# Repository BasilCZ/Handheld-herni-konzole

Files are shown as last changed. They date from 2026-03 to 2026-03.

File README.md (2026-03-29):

# Vlastní Handheld herní konzole 

Fotka dokončené konzole

## O projektu
Tento repozitář obsahuje seznam všech součástek, 3D modely a zdrojové kódy pro vlastnoručně postavenou přenosnou herní konzoli poháněnou počítačem **Raspberry Pi 5**.

### Technické úkoly, které jsem na projektu řešil:
* Návrh a 3D tisk vlastní krabičky pro konzoli.
* Propojení **Raspberry Pi 5** s 5" kapacitním dotykovým displejem a 15 fyzickými mikrospínači přes GPIO rozhraní.
* Návrh napájení pomocí 3,7V 8000mAh Li-Pol baterie.
* Zapojení audia (8Ω 2W reproduktor Waveshare) a řešení odvodu tepla (52Pi aktivní chladič).
* Vývoj hlavní softwarové logiky a ovládání v **Pythonu**.

## Struktura repozitáře

### Hardware
Fyzické komponenty a návrh zapojení najdete ve složce `/hardware/`:
* `Seznam součástek.csv` a `Seznam součástek.xlsx` - Kompletní seznam součástek + kde je koupit/sehnat

### 3D Modely
Soubory pro výrobu krabičky najdete ve složce `/3d-modely/`:
* `Dolní část krabičky.stl` a `Horní část krabičky.stl` - Modely připravené pro 3D tisk.

### Software (Zdrojové kódy)
* `/src/` - Zde se nachází zdrojový kód, který spravuje veškerou logiku ovladače

### Docs (Dokumentace)
* Ukazuje postupný vývoj herní konzole

## Použité technologie
* **Hardware:** Raspberry Pi 5 (Single Board Computer), GPIO rozhraní, Pájení elektroniky
* **Software:** Python, OS Linux (Raspberry Pi OS)
* **Konstrukce:** 3D modelování, 3D tisk

---
*Vytvořil Ondřej Kučera (2025/2026) - Student IT na SPŠE Ječná*

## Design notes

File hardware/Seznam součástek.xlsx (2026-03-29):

Množství | Název součástky | Odkaz | Poznámky
1 | Raspberry Pi 5 - 8GB RAM | https://rpishop.cz/raspberry-pi-5/6498-raspberry-pi-5-8gb-ram.html | Stačí 4GB verze
2 | Li-Pol nabíjecí baterie 3,7 V / 8000 mAh | https://rpishop.cz/535791/li-pol-nabijeci-baterie-37-v-8000-mah/ | Stačí jen jedna
1 | 52Pi - Tenký chladicí ventilátor pro Raspberry Pi 5 | https://rpishop.cz/625761/52pi-tenky-chladici-ventilator-pro-raspberry-pi-5/
15 | Mikrospínač, černá | https://rpishop.cz/tlacitka-spinace/1320-mikrospinac-cerna.html
1 | Raspberry Pi Touch Display 2 - 5”, 720 × 1280, kapacitní, DSI | https://rpishop.cz/610722/raspberry-pi-touch-display-2-5-portrait/
1 | Raspberry Pi 5 RTC baterie | https://rpishop.cz/knoflikove/6499-raspberry-pi-5-rtc-baterie.html | Není potřeba
1 | Raspberry Pi 5 Display Cable Standard - Mini, 300 mm | https://rpishop.cz/mipi/6505-raspberry-pi-5-display-cable-standard-mini-300-mm.html | Kabel který je dodán s displejem není dostatečně dlouhý, proto je potřeba jej dokoupit
1 | Waveshare 8Ω 2W Reproduktor | https://rpishop.cz/623664/waveshare-8ω-2w-reproduktor/ | Je to sada dvou reproduktorů, proto jen jeden
1 | Raspberry Pi 27W USB-C napájecí zdroj, EU, bílý | https://rpishop.cz/zdroje-s-usb-c-kabelem/6494-raspberry-pi-27w-usb-c-napajeci-zdroj-eu-bily.html | Jestli máte nějakou nabíječku od starého mobilu, lze použít
1 | Knoflík pro mikrospínač, zelený, 8 mm | https://rpishop.cz/606291/knoflik-pro-mikrospinac-zeleny-8-mm/ | Čistě jen pro design
1 | Knoflík pro mikrospínač, žlutý, 8 mm | https://rpishop.cz/606292/knoflik-pro-mikrospinac-zluty-8-mm/ | Čistě jen pro design
1 | Knoflík pro mikrospínač, modrý, 8 mm | https://rpishop.cz/606289/knoflik-pro-mikrospinac-8-mm/ | Čistě jen pro design
1 | Knoflík pro mikrospínač, červený, 8 mm | https://rpishop.cz/606288/knoflik-pro-mikrospinac-cerveny-8-mm/ | Čistě jen pro design
8 | Knoflík pro mikrospínač, černý, 8 mm | https://rpishop.cz/660937/knoflik-pro-mikrospinac-cerny-8-mm/ | Čistě jen pro design
1 | A / C převodník MCP3008 10bitový 8kanálový SPI - DIP | https://botland.cz/prevadece/2358-a-c-prevodnik-mcp3008-10bitovy-8kanalovy-spi-dip-5904422362089.html | K překládání analogových signálů na digitální data
1 | LaskaKit Sada smršťovacích bužírek v boxu 560ks | https://www.laskakit.cz/laskakit-sada-smrstovacich-buzirek-v-boxu-560ks/
2 | MAX98357 I2S mono zesilovač 3W | https://www.laskakit.cz/max98357-i2s-mono-zesilovac-3w/
1 | DuPont kabel M-F - 40x, 40 cm | https://dratek.cz/arduino-platforma/121747-40-x-m-f-dupont-kabel-40-cm.html
2 | JST XH 2,54 mm 2-Pin vodič samice | https://dratek.cz/arduino-platforma/3178-jst-xh-2.54mm-2-pin-vodic-samice.html
1 | DuPont kabel M-M - 40x, 20 cm | https://dratek.cz/arduino-platforma/1063-eses-40-x-m-m-dupont-kabel.html
2 | Joystick pro PS2 | https://dratek.cz/arduino-platforma/884-joystick-ps2.html
1 | DuPont kabel F-F - 40x, 20 cm | https://dratek.cz/arduino-platforma/835-eses-40-x-f-f-dupont-kabel.html
1 | Metalizovaný rezistor 330K - 0,25W 1% | https://dratek.cz/arduino-platforma/174965-metalizovany-rezistor-330k-0-25w-1.html
2 | Univerzální plošný spoj - 50 x 70 mm | https://dratek.cz/arduino-platforma/843-univerzalni-plosny-spoj-50mm-x-70mm.html
1 | Geekworm X1203 5.1V 5A UPS Shield for Raspberry Pi 5 Series | https://geekworm.com/products/x1203

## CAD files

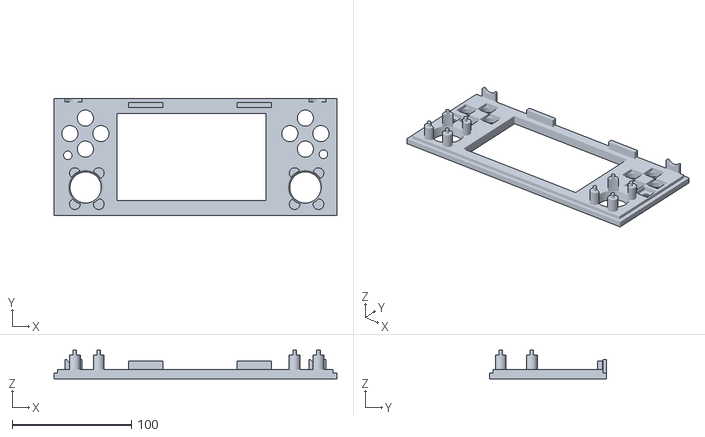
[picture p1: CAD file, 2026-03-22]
3d-modely/Horní část krabičky.stl
237.0 x 98.0 x 24.0

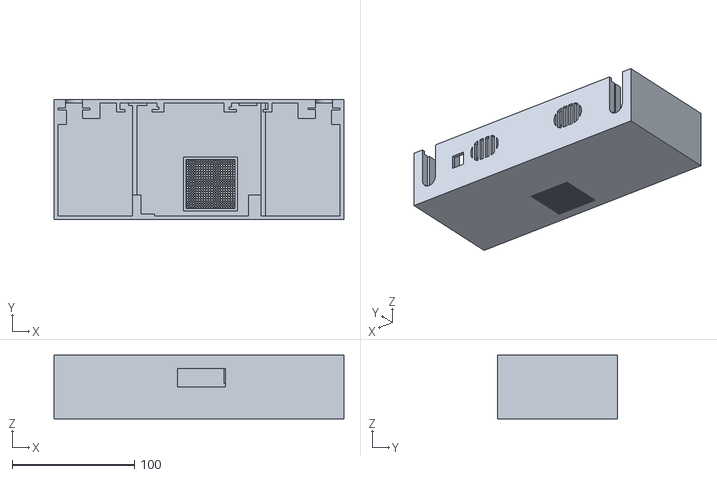
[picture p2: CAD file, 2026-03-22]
3d-modely/Dolní část krabičky.stl
237.0 x 98.0 x 52.0

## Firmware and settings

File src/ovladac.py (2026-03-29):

import evdev
from evdev import UInput, ecodes, AbsInfo
from gpiozero import Button, MCP3008
import time

# Inicializace GPIO pinů
btn_up = Button(27)
btn_down = Button(17)
btn_left = Button(5)
btn_right = Button(22)

btn_a = Button(13)
btn_b = Button(26)
btn_x = Button(20)
btn_y = Button(12)

btn_l1 = Button(24)
btn_l2 = Button(23)
btn_r1 = Button(7)
btn_r2 = Button(25)

btn_select = Button(15)
btn_start = Button(14)

btn_l3 = Button(3)
btn_r3 = Button(2)

# Pravý joystick
joy_R_X = MCP3008(channel=0)
joy_R_Y = MCP3008(channel=1)

# Levý joystick
joy_L_Y = MCP3008(channel=3)
joy_L_X = MCP3008(channel=2)

# Vytvoření gamepadu
cap = {
    ecodes.EV_KEY: [
        ecodes.BTN_A, ecodes.BTN_B, ecodes.BTN_X, ecodes.BTN_Y,
        ecodes.BTN_TL, ecodes.BTN_TR, ecodes.BTN_TL2, ecodes.BTN_TR2,
        ecodes.BTN_THUMBL, ecodes.BTN_THUMBR,
        ecodes.BTN_START, ecodes.BTN_SELECT, ecodes.BTN_MODE,
    ],
    ecodes.EV_ABS: [
        (ecodes.ABS_X, AbsInfo(value=127, min=0, max=255, fuzz=0, flat=15, resolution=0)),
        (ecodes.ABS_Y, AbsInfo(value=127, min=0, max=255, fuzz=0, flat=15, resolution=0)),
        (ecodes.ABS_Z, AbsInfo(value=0, min=0, max=255, fuzz=0, flat=0, resolution=0)),   # Levý trigger (L2)
        (ecodes.ABS_RX, AbsInfo(value=127, min=0, max=255, fuzz=0, flat=15, resolution=0)),
        (ecodes.ABS_RY, AbsInfo(value=127, min=0, max=255, fuzz=0, flat=15, resolution=0)),
        (ecodes.ABS_RZ, AbsInfo(value=0, min=0, max=255, fuzz=0, flat=0, resolution=0)),  # Pravý trigger (R2)
        (ecodes.ABS_HAT0X, AbsInfo(value=0, min=-1, max=1, fuzz=0, flat=0, resolution=0)),
        (ecodes.ABS_HAT0Y, AbsInfo(value=0, min=-1, max=1, fuzz=0, flat=0, resolution=0)),
    ]
}

ui = UInput(cap, name="Xbox Gamepad", vendor=0x045e, product=0x028e)
# Vendor je Microsoft
# Product je Xbox 360 ovladač
def stav(tlacitko):
    return 1 if tlacitko.is_pressed else 0

def packa(mcp_kanal):
    return int(mcp_kanal.value * 255)

start_zmacknuto = False
start_cas = 0
home_odeslano = False

try:
    while True:
        # Start a home tlačítka
        if btn_start.is_pressed:
            if not start_zmacknuto:
                start_zmacknuto = True
                start_cas = time.time()
                home_odeslano = False
            else:
                if (time.time() - start_cas) >= 1.0 and not home_odeslano:
                    ui.write(ecodes.EV_KEY, ecodes.BTN_MODE, 1)
                    ui.syn()
                    home_odeslano = True
        else:
            if start_zmacknuto:
                # Právě jsi to pustil
                if home_odeslano:
                    ui.write(ecodes.EV_KEY, ecodes.BTN_MODE, 0) # Pustit Home
                else:
                    # Bylo to kratší než vteřina -> Odeslat krátký START klik
                    ui.write(ecodes.EV_KEY, ecodes.BTN_START, 1)
                    ui.syn()
                    time.sleep(0.05)
                    ui.write(ecodes.EV_KEY, ecodes.BTN_START, 0)
                ui.syn()
                start_zmacknuto = False

        # Obyčejná tlačítka
        ui.write(ecodes.EV_KEY, ecodes.BTN_A, stav(btn_a))
        ui.write(ecodes.EV_KEY, ecodes.BTN_B, stav(btn_b))
        ui.write(ecodes.EV_KEY, ecodes.BTN_X, stav(btn_x))
        ui.write(ecodes.EV_KEY, ecodes.BTN_Y, stav(btn_y))
        
        ui.write(ecodes.EV_KEY, ecodes.BTN_TL, stav(btn_l1))
        ui.write(ecodes.EV_KEY, ecodes.BTN_TR, stav(btn_r1))
        ui.write(ecodes.EV_KEY, ecodes.BTN_TL2, stav(btn_l2))
        ui.write(ecodes.EV_KEY, ecodes.BTN_TR2, stav(btn_r2))

        # Analogových triggery (L2 a R2)
        ui.write(ecodes.EV_ABS, ecodes.ABS_Z, 255 if btn_l2.is_pressed else 0)
        ui.write(ecodes.EV_ABS, ecodes.ABS_RZ, 255 if btn_r2.is_pressed else 0)
        
        ui.write(ecodes.EV_KEY, ecodes.BTN_THUMBL, stav(btn_l3))
        ui.write(ecodes.EV_KEY, ecodes.BTN_THUMBR, stav(btn_r3))
        ui.write(ecodes.EV_KEY, ecodes.BTN_SELECT, stav(btn_select))
        
        # D-PAD
        hat_x = 0
        if btn_left.is_pressed: hat_x = -1
        elif btn_right.is_pressed: hat_x = 1
        
        hat_y = 0
        if btn_up.is_pressed: hat_y = -1
        elif btn_down.is_pressed: hat_y = 1
        
        ui.write(ecodes.EV_ABS, ecodes.ABS_HAT0X, hat_x)
        ui.write(ecodes.EV_ABS, ecodes.ABS_HAT0Y, hat_y)
        
        # Analogové páčky
        ui.write(ecodes.EV_ABS, ecodes.ABS_X, 255 - packa(joy_L_Y))
        ui.write(ecodes.EV_ABS, ecodes.ABS_Y, packa(joy_L_X))
        ui.write(ecodes.EV_ABS, ecodes.ABS_RX, 255 - packa(joy_R_Y))
        ui.write(ecodes.EV_ABS, ecodes.ABS_RY, packa(joy_R_X))
        
        # Odeslání všech změn do systému
        ui.syn()
        
        time.sleep(0.01)

except KeyboardInterrupt:
    pass

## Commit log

2026-03-22 Přidání 3D modelů krabičky
    [Dolní část krabičky.stl, Horní část krabičky.stl]
2026-03-29 Přidání 3d modelů
    [Dolní část krabičky.stl, Horní část krabičky.stl]
2026-03-29 Smazání Dolní část krabičky.stl
    [Dolní část krabičky.stl]
2026-03-29 Smazání Horní část krabičky.stl
    [Horní část krabičky.stl]
2026-03-29 Přidání listu použitých součástek
    [Seznam součástek.csv]
2026-03-29 Přidání seznamu součástek v xlsx formátu
    [Seznam součástek.xlsx]
